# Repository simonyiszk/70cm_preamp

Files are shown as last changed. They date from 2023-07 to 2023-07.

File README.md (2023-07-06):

Előerősítő 70 cm-es sávra
===========

# Specifikáció
* 435 MHz középfrekcencia
* 23 MHz sávszélesség

# v02 változások
* Új erősítő: PGA-103+
* Új szűrő: SF2446E
* Kapcsrajz szimbólumok külön könyvtárba rendszerezése
* Rajzolatok külön könyvtárba rendszerezése
* cache fájlok hozzáadása .gitignore-hoz
* Bias Tee (tápfeladó)
* "RF" megjelölésű alkatrészek: rezonanciafrekvenciájuk kritikus

# PGA-103+
* Új erősítő: PGA-103+
* Új szűrő: SF2446E

# Megjegyzés
A 'lib-table' fájlok hozzáadják a kapcsrajz szimbólum és rajzolatokat tartalmazó fájlokat a könyvtárak közé.
Amennyiben ez mégsem történik meg, ezt manuálisan kell megtenni.

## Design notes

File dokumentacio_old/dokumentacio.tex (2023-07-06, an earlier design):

\begin{center}
	
	\Huge
	Előerősítő 70\,cm-es sávra
	
	\Large
	\url{https://github.com/simonyiszk/70cm_preamp}
	
	\Large
	HA5KFU projekt
	
	\Large
	Kiss Ádám (HA8KDA), Bazsó Márton (HA7BM), \\ Keresztes Botond, Agócs Dániel, Pápay Levente (HA3PL)
\end{center}

\tableofcontents

\listoffigures

\newpage

\section{Célkitűzés}
\label{sec:celkituzes}

Az erősítő hivatása, hogy a Schönherz kollégium tetejére telepített 70\,cm-es sávra készült antenna által fogott jeleket erősítse, közülük is elsősorban a SMOG-1 műholdét 437,345\,MHz-en.

\section{Kapcsolás}
\label{sec:kapcsolas}

Mivel az erősítő egy rádiófrekvencián elég \enquote{szennyezett} környékre kerül felszerelésre, így fontos egy jó szűrő alkalmazása ebben a fokozatban. Az akusztikus felületi hullámszűrők kitűnőek ilyen feladatokra, ugyanis nagyon meredek levágást biztosítanak a sávszéleken. Egy ilyen alkatrészt fellelni sem volt egyszerű, de beszerezni még bonyolultabbnak bizonyult, de végül a mouseren keresztül valahogyan sikerült. A választás az SF2446E\cite{SAW} néven futó áramkörre esett, melynek a minimum beszerzési mennyisége 10\,db volt.

Mint a legtöbb vételi berendezésben, itt is egy alacsony zajú előerősítő kerül a vételi lánc elejére. Előzőekben már épült egy hasonló kapcsolás egy ADL5523\cite{ADL}-as IC felhasználásával, de amikor kiderült, hogy az akusztikus szűrőből minimum 10-et kell rendelnünk, felmerült az ötlet, hogy gyártsunk le 10\,db áramkört, és a maradékra majd valahonnan kerítünk vevőt -- végül nem kellett sokat keresni, a nagy részük elkelt a klubon belül. Erősítőnek végül a Mini-Circuits PGA-103+\cite{PGA} terméke került kiválasztásra -- szintén a mouserről -- ugyanis kellően alacsony a zajtényezője, valamint 22\,dB erősítést ígér 400\,MHz-en, és végül, de nem utolsó sorban olcsóbb, mint egy ADL5523\cite{ADL}-as.

\begin{figure}[!ht]
	\centering
	
	\caption{Az előerősítő kapcsolása}
	\label{fig:LNA_sch}
\end{figure}

Alapesetben az erősítő a szűrő elé kerülne, ugyanis az eredő rendszernek így kedvezőbb lesz a jel-zaj viszonya. Viszont mint említésre került, a telepítési hely RF szempontból elég \enquote{szennyezett}, így félő, hogy a nagy sávszélességű erősítőnket könnyen túlvezérlik a számunkra érdektelen jelek. Ebből a meggondolásból a szűrőt az erősítő elé helyeztük, hogy csökkentsük a bele jutó összteljesítményt.

Amikor a NYÁK már majdnem gyártásba lett adva, Levente felhívta a figyelmünket egy kiegészítő dokumentumra\cite{PGA_comp}, mely az erősítőhöz megad egy kompenzáló hálózatot, ugyanis nélküle az áramkör 100\,MHz alatt nem lenne stabil. Így ez a 3 passzív alkatrészből álló kiegészítés az utolsó pillanatban még a tervre került. A végleges kapcsolás az \ref{fig:LNA_sch}-es ábrán látható.

\section{NYÁK}
\label{sec:nyak}

A hordozót elég kis méretűre meg lehetett csinálni, ugyanis mindösszesen 7 alkatrészt tartalmaz. A jelet vivő tápvonal úgy lett kialakítva, hogy a hullámimpedanciája 50\,$\Omega$-os legyen, ez főként azért lett ilyenre megcsinálva, hogy Marci gyakorolja CST-s szimulációs képességeit. Az elkészült rajzolat a \ref{fig:nyak}-es ábrán látható, mely egy kétrétegű, 1\,mm vastag hordozóra lett elkészítve.

\begin{figure}[!ht]
	\centering
	\begin{subfigure}[b]{0.49\textwidth}
		
		\caption{NYÁK eleje}
		\label{fig:nyak_elol}
	\end{subfigure}
	\begin{subfigure}[b]{0.49\textwidth}
		
		\caption{NYÁK hátulja}
		\label{fig:nyak_hatul}
	\end{subfigure}
	\caption{NYÁK terv a KiCAD 3D nézetében}
	\label{fig:nyak}
\end{figure}

Némi megfontolást igényelt, hogy az áramkörünk hordozóját az Elektronikai Technológia Tanszéken, vagy egy keleti üzemben gyártassuk le. A döntő szempont végül a sebesség volt, ugyanis a SMOG-1 indítása rohamosan közeledett, és szerettünk volna elkészülni vele, így az ETT-re esett a választás, ugyanis a keletről történő postázás időtartama viszonylag hosszú és olykor kiszámíthatatlan.

\section{Mérés 1}
\label{sec:meres1}

Miután elkészült néhány példány az áramkörből, ezek bemérésre kerültek a BME V1 épületében található Rohde \& Schwarz laboratóriumban. A méréshez használt eszközök egy R\&S ZVRE vektor hálózat analizátor, illetve egy R\&S ESCS30 típusú jelanalizátor, mellyel gerjedést mértünk a 100\,kHz - 1\,GHz tartományon -- utóbbi mérési eredmények külön nem kerültek elmentésre. Az áramkörök táplálásához Yume tápfeladóját, egy LM7805-öst, és egy R\&S NGMO2-es típusú labortápot használtunk, melynek kimenetét 8\,V-ra állítottuk.

A bemért áramkörök:

\begin{itemize}
	\item \#1: Szűrő + erősítő + kompenzáló hálózat
	\item \#2: Szűrő + erősítő + kompenzáló hálózat
	\item \#2.5: \#2-es áramkör javítás után (erősítő nem megfelelő forrasztása)
	\item \#3: Szűrő + erősítő
\end{itemize}

\newpage

Mivel a klubban nem voltak fellelhetők a kompenzáló hálózathoz szükséges pontos értékek, így az a következő értékekkel lett megvalósítva:

\begin{itemize}
	\item L1 220\,nH
	\item R1 150\,$\Omega$
	\item C1 330\,pF
\end{itemize}

Az áramkörökről összesen 14 mérés készült (ebből 13-at el is mentettünk, az utolsót elfelejtettük). A következőkben a legfontosabbak kerülnek ismertetésre, a többit pedig a Függelék (\ref{sec:fuggelek}) tartalmazza.

\subsection{\#1-es áramkör}
\label{subsec:1es_aramkor}

A \ref{fig:erosito1}-as ábrán az áramkör átvitele ($S_{21}$ paraméter) látható.

\begin{figure}[!ht]
	\centering
	
	\caption{\#1-es erősítő átvitele}
	\label{fig:erosito1}
\end{figure}

A mérés nagyságrendileg megegyezik az elvárásokkal. Az erősítőtől ebben a tartományban 22\,dB erősítést várunk, míg a szűrő nagyjából 2\,dB-t csillapít, avagy közel a várt eredményt kaptuk. A sávszélesség is jól egyezik a szűrő adatlapjában\cite{SAW} megadott 23\,MHz-el. Az erősítő áramfelvétele is (95\,mA) közel van az adatlapi\cite{PGA} értékhez, így összességében kijelenthető, hogy az áramkör az elvártnak megfelelően működik.

A vizsgálatok során nem találtunk gerjedésre utaló jeleket, így kijelenthető az is, hogy az alternatív értékekből összerakott kompenzáló hálózat is megfelelően ellátja feladatát.

%\newpage

\subsection{\#2-es áramkör}
\label{subsec:2es_aramkor}

Ez az áramkör először nem működött rendeltetésszerűen, ugyanis az erősítése gyanúsan alacsony volt. Egy gyors mikroszkóp alatti szemrevételezés után kiderült, hogy ennek oka, a nem megfelelően beforrasztott erősítő volt. A hiba javítása után a \ref{fig:erosito2}-es ábrán látható átvitelt kaptuk.

\begin{figure}[!ht]
	\centering
	
	\caption{\#2.5-ös erősítő átvitele}
	\label{fig:erosito2}
\end{figure}

Látható, hogy az átvitel jellege megegyezik az \#1-es áramkörnél mérttel, így erről is elmondható, hogy megfelelően működik. Ez a kapcsolás eleinte mutatott gerjedés gyanús jeleket, melyeket a későbbiek során nem sikerült reprodukálnunk. Feltételezhetően a spektrumbeli kitüremkedések egy tranziensjelenség miatt következtek be. A további mérések során az áramkör stabilnak bizonyult.

\subsection{\#3-as áramkör}
\label{3as_aramkor}

Miután megtaláltuk a kiegészítőt az adatlaphoz\cite{PGA_comp}, kíváncsiak voltunk, hogy vajon hogyan viselkedne az áramkör, ha nem építjük bele az ajánlott kompenzáló hálózatot. Ezért a harmadik áramkör csak a szűrőt és az erősítőt tartalmazta. A mérés eredménye a \ref{fig:erosito3}-ös ábrán látható.

\begin{figure}[!ht]
	\centering
	
	\caption{\#3-as erősítő átvitele}
	\label{fig:erosito3}
\end{figure}

Megfigyelhető, hogy a szűrő amplitúdómenete az áteresztő sávban jóval hullámosabb az adatlapban\,\cite{SAW} és az előző mérésekben látottnál. Ez a szűrő illesztetlenségére utalhat, ami azért különös, mert elméletileg minden eszközünk ki- és bemeneti impedanciája is 50\,$\Omega$-os. Látható az is, hogy az erősítő bekapcsolásakor is csak -10\,dB az átvitel, ami nem éppen nevezhető erősítőnek. Ezt a kapcsolást is megvizsgáltuk gerjedés szempontjából, de itt sem tapasztaltunk semmi ráutaló jelet.

1-2 nappal a mérések után felmerült bennem, hogy lehet, ennél a kapcsolásnál is volt nem megfelelő forrasztás, ugyanis szerintem a kompenzáló hálózat hiányának nem szabadna ekkora csillapítást okoznia (30\,dB-lel voltunk az elvárt szint alatt). A szűrőnek a megváltozott amplitúdómenetéből valószínűsíthető, hogy összességében a kompenzálóhálózat hiánya befolyással van az áramkör viselkedésére, viszont nem zárható ki, hogy volt egyéb tényező -- a kiegészítő hálózaton kívül -- ami befolyásolta az eredményt. Ezért nem jelenthető ki egyértelműen, hogy ez a mérés a kompenzáló hálózat átvitelre gyakorolt hatását szemlélteti.

\section{Mérés 2}
\label{sec:meres2}

Miután az első mérésekkel igazoltuk, hogy az alapkoncepció működőképes, megrendeltük a szükséges passzív alkatrészeket és csatlakozókat\cite{90es_SMA}, majd ismét beköltöztünk egy délután erejéig a BME V1 épületében található Rohde \& Schwarz laboratóriumba, hogy beforrasszuk az áramköröket, és méréssel igazoljuk működésüket.

A méréshez használt eszközök egy R\&S ZVRE vektor hálózat analizátor, illetve egy R\&S ESCS30 típusú jelanalizátor, mellyel gerjedést mértünk a 100\,kHz - 1\,GHz tartományon -- utóbbi mérési eredmények külön nem kerültek elmentésre. Az áramkörök táplálásához Yume tápfeladóját, egy LM7805-öst, és egy R\&S NGMO2-es típusú labortápot használtunk, melynek kimenetét 8\,V-ra állítottuk. A mérési elrendezés a \ref{fig:elrendezes}-es ábrán látható -- a labortápot leszámítva.

\begin{figure}[!ht]
	\centering
	\begin{minipage}[b]{0.49\textwidth}
		
		\caption{Egy beforrasztott áramkör}
		\label{fig:beforrasztott}
	\end{minipage}
	\begin{minipage}[b]{0.49\textwidth}
		
		\caption{Mérési elrendezés}
		\label{fig:elrendezes}
	\end{minipage}
\end{figure}

A módszertanon annyit változtattunk az előző alkalomhoz képest, hogy a VNA-t úgy kalibráltuk, hogy a két portját összecsatoltuk, közbeiktatva a tápfeladót, és rákapcsolva a tápegységet. Így -- mint látni fogjuk -- a várthoz közelebbi eredményeket kaptunk, mint előző alkalommal, amikor csak a mérőkábelek lettek kikompenzálva.

Mivel a Lomex-ben nem voltak kaphatók pont azok az értékek, melyeket az előzőekben kipróbáltunk, így a kompenzáló hálózat értékei a következők lettek:

\begin{itemize}
	\item L1 330\,nH\cite{L1}
	\item R1 150\,$\Omega$\cite{R1}
	\item C1 330\,pF\cite{C1}
\end{itemize}

Az alábbi áramkörök kerültek megépítésre és bemérésre (az összes alkatrészt tartalmazzák, kivétel ahol másként van feltüntetve):

\begin{itemize}
\item \#0: \#7-es áramkör kompenzálóhálózat nélkül
\item \#2.5: lásd: \ref{sec:meres1} és \ref{subsec:2es_aramkor} pont
\item \#3.5: \#3-as áramkör javítás után (szűrő nem megfelelő forrasztása)
\item \#4
\item \#5
\item \#6
\item \#7
\item \#8
\end{itemize}

A nap végére az összes beforrasztott áramkör működőképes volt, és az elvártnak megfelelően üzemelt.

Mivel kiderült, hogy az előző alkalommal valóban egy rosszul beforrasztott áramkörön tanulmányoztuk a kompenzáló hálózat hatását, így megismételtük a mérést, ezúttal különös tekintettel a forrasztásra. A mérési eredményeket a \ref{fig:kompenzalo_halozat}-as ábra veti össze.

\begin{figure}[!ht]
	\centering
	\begin{subfigure}[b]{\textwidth}
		
		\caption{Kompenzáló hálózat nélkül}
		\label{fig:erosito0}
	\end{subfigure}
	\begin{subfigure}[b]{\textwidth}
		
		\caption{Kompenzáló hálózattal}
		\label{fig:erosito7}
	\end{subfigure}
	\caption{Kompenzálás hatásának vizsgálata}
	\label{fig:kompenzalo_halozat}
\end{figure}

Látható, hogy a két áramkör között nincsen jelentős eltérés az átviteli sávban, mindössze annyi különbség figyelhető meg, hogy a \ref{fig:erosito0} esetben az áteresztő sáv enyhén felfelé tolódott el frekvenciatartományban. A jelanalizátoron végzett mérés sem mutatott észlelhető gerjedést a 100\,kHz - 1\,GHz-es tartományban.

Végeredményben a mi méréseink alapján ezen alkalmazáshoz nem nélkülözhetetlen a kompenzáló hálózat, ennek ellenére az ajánlásnak megfelelően beforrasztottuk őket.

\subsection{Árnyékolás}
\label{subsec:arnyekolas}

Mivel a HA5KFU-nak gyártott példány egy erősen \enquote{RF szennyezett} környezetbe kerül -- Schönherz teteje -- így úgy döntöttünk, hogy a tetőre kerülő példányt (\#3.5-ös áramkör) bedobozoljuk, hogy védjük ezen zavarok ellen. Az árnyékoló dobozba\cite{doboz} szerelt áramkör a \ref{fig:arnyekolas}-es ábrán látható (az egyes csatlakozók funkcióját természetesen feliratozással jeleztük a szintén az ábrán látható alkoholos filctollal). Az egyszerűbb dobozolás érdekében itt a korábban látott $90^{\circ}$-os SMA csatlakozók helyett egyeneseket használtunk\cite{egyenes_SMA}.

\begin{figure}[!ht]
	\centering
	
	\caption{Az árnyékolt erősítő}
	\label{fig:arnyekolas}
\end{figure}

A jelanalizátorral végzett mérések a következő eredményt adták:

Árnyékolás nélkül a spektrumban kb. -80\,dBm szintű csúcsok láthatóak 100\,MHz, 800\,MHz és 900\,MHz környékén, melyek rendre az FM adók, LTE hálózat illetve a GSM hálózat. Az árnyékolt áramkör összeszedett zavarait nem tudtuk kimutatni, ugyanis nem türemkedtek az analizátor -90\,dBm-es zajszintje fölé.

A mérés alapján kijelenthető, hogy az árnyékolás kedvező hatással van a zajszintre, az összeszedett zavarok szintjét -90\,dBm alá csökkentette (a mérés helyszínén).

\subsection{Ellenpárhuzamos diódapár}
\label{subsec:diodak}

Tartunk tőle, hogy a tetőre kihelyezett gamma illesztésű antenna elektrosztatikusan feltöltődik, és egy esetleges kisülés károsítja a felületi szűrőnket. Ennek orvoslására egy ellentétes polaritással bekötött diódapárt helyeztünk a szűrő elé (a \ref{fig:diodak}-es ábrának megfelelően), hogy az esetlegesen felgyülemlő töltéseket ki tudja egyenlíteni. A választásnál fontos volt, hogy kis kapacitású diódákat\cite{dioda} használjunk, mivel ezek esetlegesen elhangolhatnák a szűrőt, és az átviteli sávot.

\begin{figure}[!ht]
	\centering
	
	\caption{Nem párhuzamos diódapár}
	\label{fig:diodak}
\end{figure}

Mivel ez egy utólagos ötlet volt, így ezen alkatrészeknek nem lett külön hely kialakítva a NYÁK-on, hanem a csatlakozó lábai közé lettek \enquote{begányolva}.

A beépítés utáni mérések azt mutatták, hogy a beiktatott diódák nem befolyásolják kimutatható mértékben az erősítő átvitelét.

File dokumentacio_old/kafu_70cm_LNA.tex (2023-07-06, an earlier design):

\documentclass[12pt,a4paper,oneside]{article}
\usepackage{geometry}
	\geometry                  %margók és lapméret beállítása
		{
			a4paper,
			top=20mm,
			bottom=25mm,
			left=25mm,
			right=25mm
		}
	\pagestyle{plain}           %fejléc üres, lábléc az oldalszámot tartalmazza
\usepackage{setspace}           %sorközt lehet beállítani
	\singlespacing              %egyszeres sorköz
\usepackage{indentfirst}        %bekezdések formázása
	\setlength{\parindent}{1em} %bekezdés első sorának behúzása
	\setlength{\parskip}{6pt}   %bekezdések közötti távolság
\usepackage[autostyle]{csquotes}%idézőjelek helyes formázásához
	
\usepackage[utf8]{inputenc}     %karakterkódolás
\usepackage[magyar]{babel}      %helyesírás-ellenőrzés
\usepackage[T1]{fontenc}        %szimbólumkódolás

\usepackage{amsmath}            %matematikai képletekhez
\usepackage{amssymb}            %több matematikai jelölés (automatikusan betölti az 'amsfonts' csomagot)
\usepackage{graphicx}           %képek beillesztéséhez (valószínűleg betölti a 'graphics' csomagot, de nem találtam erre egyértelmű hivatkozást)
	\graphicspath               %képek elérési útvonala, szabadon bővíthető/csökkenthető
	{
		{./}
		{./kepek/}
		{./octave/}
	}
\usepackage{enumitem}           %felsorolásokat lehet vele formázni
\usepackage{titling}            %title, author, stb. definiálásához, használatához
\usepackage{hyperref}           %a hivatkozásokat kezeli
	\hypersetup                 %a hivatkozásokat lehet formálni
	{
		colorlinks=true,        %linkek színezésének engedélyezése
		citecolor=black,        %dokumentumon belüli hivatkozás színe
		linkcolor=black,          %valami másféle dokumentumon belüli hivatkozás színe
		urlcolor=blue,          %weblaphivatkozások színe
	}
\usepackage[center]{caption}    %képaláírásokat alapból középre igazítja
\usepackage{subcaption}         %subfigure környezethez
\usepackage{float}              %'lebegő' objektumok (pl. képek, táblázatok) pozícionálására

\begin{document}
	\include{dokumentacio}
	\include{fuggelek}
\end{document}

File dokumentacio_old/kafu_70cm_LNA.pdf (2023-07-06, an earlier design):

# Előerősítő 70 cm-es sávra

## https://github.com/simonyiszk/70cm_preamp

## HA5KFU projekt

Kiss Ádám (HA8KDA), Bazsó Márton (HA7BM),

## Keresztes Botond, Agócs Dániel, Pápay Levente (HA3PL)

## Tartalomjegyzék

1. Célkitűzés | 3
2. Kapcsolás | 3
3. NYÁK | 4
4. Mérés 1 | 4
4.1. #1-es áramkör | | 5
4.2. #2-es áramkör | | 5
4.3. #3-as áramkör | | 6
5. Mérés 2 | 7
5.1. Árnyékolás | 10
5.2. Ellenpárhuzamos diódapár | 10
6. Függelék | 12
6.1. Mérési eredmények grafikusan | 13

## Ábrák jegyzéke

1. | Az előerősítő kapcsolása | | 3
2. | NYÁK terv a KiCAD 3D nézetében | | 4
3. | #1-es erősítő átvitele | | 5
4. | #2.5-ös erősítő átvitele | | 6
5. | #3-as erősítő átvitele | | 7
6. | Egy beforrasztott áramkör | | 8
7. | Mérési elrendezés | | 8
8. | Kompenzálás hatásának vizsgálata | | 9

9. Az árnyékolt erősítő | 10
10. Nem párhuzamos diódapár | 11
11. #1-es erősítő 1 MHz - 1 GHz, erősítő KI | 13
12. #1-es erősítő 400 MHz - 480 MHz, erősítő KI | 13
13. #1-es erősítő 1 MHz - 1 GHz, erősítő BE | 14
14. #1-es erősítő 400 MHz - 480 MHz, erősítő BE | 14
15. #2-es erősítő 1 MHz - 1 GHz, erősítő KI | 15
16. #2-es erősítő 400 MHz - 480 MHz, erősítő KI | 15
17. #2-es erősítő 1 MHz - 1 GHz, erősítő BE | 16
18. #2-es erősítő 400 MHz - 480 MHz, erősítő BE | 16
19. #2.5-ös erősítő 400 MHz - 480 MHz, erősítő BE | 17
20. #3-as erősítő 1 MHz - 1 GHz, erősítő KI | 17
21. #3-as erősítő 400 MHz - 480 MHz, erősítő KI | 18
22. #3-as erősítő 1 MHz - 1 GHz, erősítő BE | 18
23. #3-as erősítő 400 MHz - 480 MHz, erősítő BE | 19
24. #0-ás erősítő 1 MHz - 1 GHz, erősítő BE | 19
25. #0-ás erősítő 400 MHz - 480 MHz, erősítő BE | 20
26. #2.5-ös erősítő 1 MHz - 1 GHz, erősítő BE | 20
27. #2.5-ös erősítő 400 MHz - 480 MHz, erősítő BE | 21
28. #3.5-ös erősítő 1 MHz - 1 GHz, erősítő BE | 21
29. #3.5-ös erősítő 400 MHz - 480 MHz, erősítő BE | 22
30. #4-es erősítő 1 MHz - 1 GHz, erősítő BE | 22
31. #4-es erősítő 400 MHz - 480 MHz, erősítő BE | 23
32. #5-ös erősítő 1 MHz - 1 GHz, erősítő BE | 23
33. #5-ös erősítő 400 MHz - 480 MHz, erősítő BE | 24
34. #6-os erősítő 1 MHz - 1 GHz, erősítő BE | 24
35. #6-os erősítő 400 MHz - 480 MHz, erősítő BE | 25
36. #7-es erősítő 1 MHz - 1 GHz, erősítő BE | 25
37. #7-es erősítő 400 MHz - 480 MHz, erősítő BE | 26
38. #8-as erősítő 1 MHz - 1 GHz, erősítő BE | 26
39. #8-as erősítő 400 MHz - 480 MHz, erősítő BE | 27

## 1. Célkitűzés

Az erősítő hivatása, hogy a Schönherz kollégium tetejére telepített 70 cm-es sávra készült antenna által fogott jeleket erősítse, közülük is elsősorban a SMOG-1 műholdét 437,345 MHz-en.

## 2. Kapcsolás

Mivel az erősítő egy rádiófrekvencián elég „szennyezett” környékre kerül felszerelésre, így fontos egy jó szűrő alkalmazása ebben a fokozatban. Az akusztikus felületi hullámszűrők kitűnőek ilyen feladatokra, ugyanis nagyon meredek levágást biztosítanak a sávszéleken. Egy ilyen alkatrészt fellelni sem volt egyszerű, de beszerezni még bonyolultabbnak bizonyult, de végül a mouseren keresztül valahogyan sikerült. A választás az SF2446E[1] néven futó áramkörre esett, melynek a minimum beszerzési mennyisége 10 db volt.

Mint a legtöbb vételi berendezésben, itt is egy alacsony zajú előerősítő kerül a vételi lánc elejére. Előzőekben már épült egy hasonló kapcsolás egy ADL5523[2]-as IC felhasználásával, de amikor kiderült, hogy az akusztikus szűrőből minimum 10-et kell rendelnünk, felmerült az ötlet, hogy gyártsunk le 10 db áramkört, és a maradékra majd valahonnan kerítünk vevőt – végül nem kellett sokat keresni, a nagy részük elkelt a klubon belül. Erősítőnek végül a Mini-Circuits PGA-103+[3] terméke került kiválasztásra – szintén a mouserről – ugyanis kellően alacsony a zajtényezője, valamint 22 dB erősítést ígér 400 MHz-en, és végül, de nem utolsó sorban olcsóbb, mint egy ADL5523[2]-as.

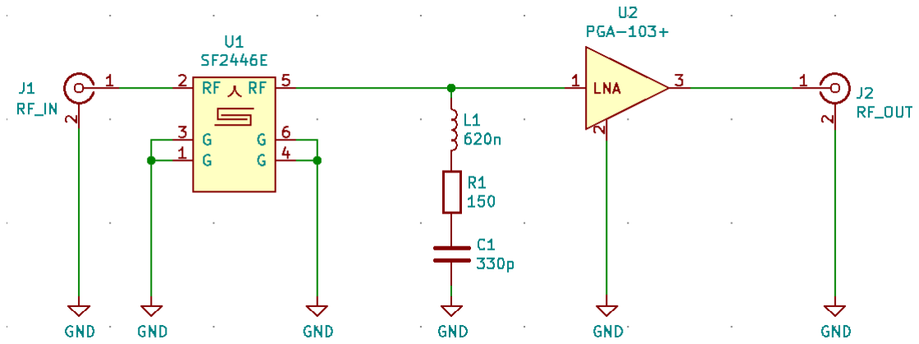
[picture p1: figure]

1. ábra. Az előerősítő kapcsolása

Alapesetben az erősítő a szűrő elé kerülne, ugyanis az eredő rendszernek így kedvezőbb lesz a jel-zaj viszonya. Viszont mint említésre került, a telepítési hely RF szempontból elég „szennyezett”, így félő, hogy a nagy sávszélességű erősítőnket könnyen túlvezérlik a számunkra érdektelen jelek. Ebből a meggondolásból a szűrőt az erősítő elé helyeztük, hogy csökkentsük a bele jutó összteljesítményt.
Amikor a NYÁK már majdnem gyártásba lett adva, Levente felhívta a figyelmünket egy kiegészítő dokumentumra[4], mely az erősítőhöz megad egy kompenzáló hálózatot, ugyanis nélküle az áramkör 100 MHz alatt nem lenne stabil. Így ez a 3 passzív alkatrészből álló kiegészítés az utolsó pillanatban még a tervre került. A végleges kapcsolás az 1-es ábrán látható.

## 3. NYÁK

A hordozót elég kis méretűre meg lehetett csinálni, ugyanis mindösszesen 7 alkatrészt tartalmaz. A jelet vivő tápvonal úgy lett kialakítva, hogy a hullámimpedanciája 50 Ω-os legyen, ez főként azért lett ilyenre megcsinálva, hogy Marci gyakorolja CST-s szimulációs képességeit. Az elkészült rajzolat a 2-es ábrán látható, mely egy kétrétegű, 1 mm vastag hordozóra lett elkészítve.

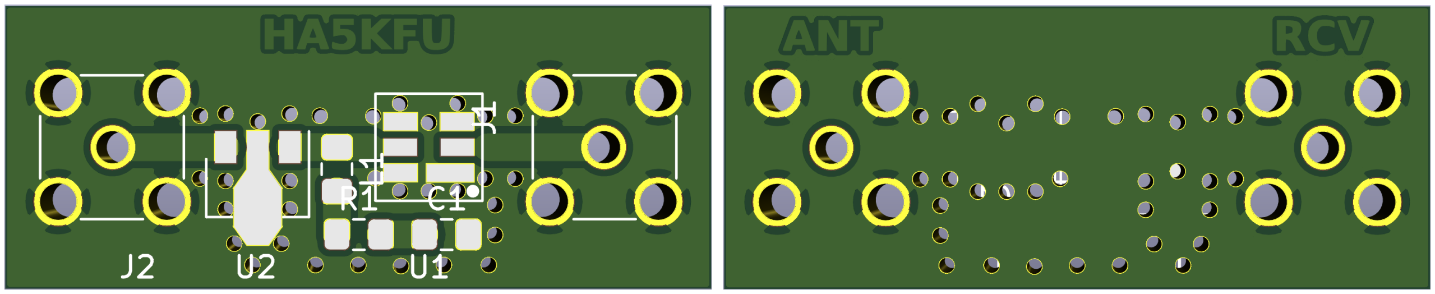
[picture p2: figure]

(a) NYÁK eleje | (b) NYÁK hátulja
2. ábra. NYÁK terv a KiCAD 3D nézetében

Némi megfontolást igényelt, hogy az áramkörünk hordozóját az Elektronikai Technológia Tanszéken, vagy egy keleti üzemben gyártassuk le. A döntő szempont végül a sebesség volt, ugyanis a SMOG-1 indítása rohamosan közeledett, és szerettünk volna elkészülni vele, így az ETT-re esett a választás, ugyanis a keletről történő postázás időtartama viszonylag hosszú és olykor kiszámíthatatlan.

## 4. Mérés 1

Miután elkészült néhány példány az áramkörből, ezek bemérésre kerültek a BME V1 épületében található Rohde & Schwarz laboratóriumban. A méréshez használt eszközök egy R&S ZVRE vektor hálózat analizátor, illetve egy R&S ESCS30 típusú jelanalizátor, mellyel gerjedést mértünk a 100 kHz - 1 GHz tartományon – utóbbi mérési eredmények külön nem kerültek elmentésre. Az áramkörök táplálásához Yume tápfeladóját, egy LM7805-öst, és egy R&S NGMO2-es típusú labortápot használtunk, melynek kimenetét 8 V-ra állítottuk.

A bemért áramkörök:

- #1: Szűrő + erősítő + kompenzáló hálózat
- #2: Szűrő + erősítő + kompenzáló hálózat
- #2.5: #2-es áramkör javítás után (erősítő nem megfelelő forrasztása)
- #3: Szűrő + erősítő

Mivel a klubban nem voltak fellelhetők a kompenzáló hálózathoz szükséges pontos értékek, így az a következő értékekkel lett megvalósítva:

- L1 220 nH
- R1 150 Ω
- C1 330 pF

Az áramkörökről összesen 14 mérés készült (ebből 13-at el is mentettünk, az utolsót elfelejtettük). A következőkben a legfontosabbak kerülnek ismertetésre, a többit pedig a Függelék (6) tartalmazza.

4.1. #1-es áramkör

A 3-as ábrán az áramkör átvitele (S21 paraméter) látható.

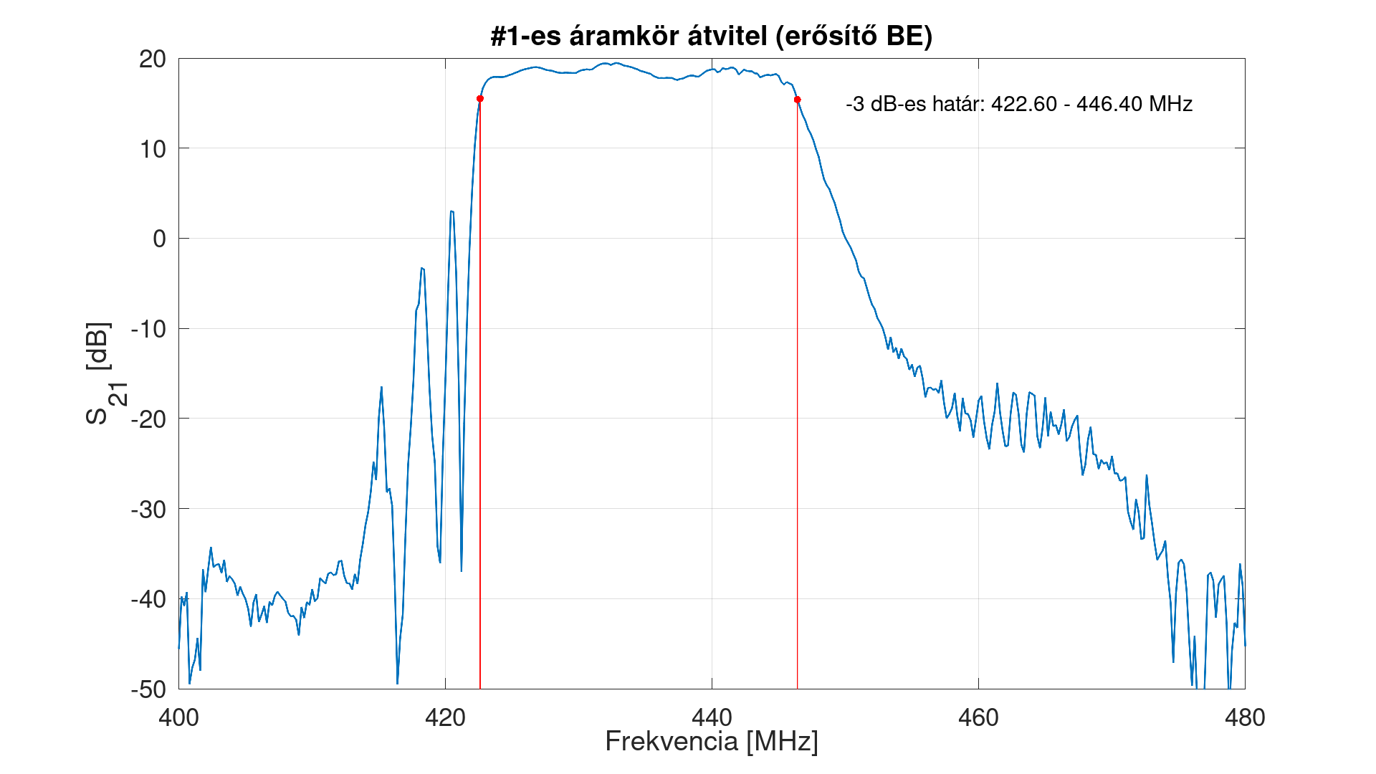
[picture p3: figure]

3. ábra. #1-es erősítő átvitele

A mérés nagyságrendileg megegyezik az elvárásokkal. Az erősítőtől ebben a tartományban 22 dB erősítést várunk, míg a szűrő nagyjából 2 dB-t csillapít, avagy közel a várt eredményt kaptuk. A sávszélesség is jól egyezik a szűrő adatlapjában[1] megadott 23 MHz-el. Az erősítő áramfelvétele is (95 mA) közel van az adatlapi[3] értékhez, így összességében kijelenthető, hogy az áramkör az elvártnak megfelelően működik.

A vizsgálatok során nem találtunk gerjedésre utaló jeleket, így kijelenthető az is, hogy az alternatív értékekből összerakott kompenzáló hálózat is megfelelően ellátja feladatát.

4.2. #2-es áramkör

Ez az áramkör először nem működött rendeltetésszerűen, ugyanis az erősítése gyanúsan alacsony volt. Egy gyors mikroszkóp alatti szemrevételezés után kiderült, hogy ennek oka, a nem megfelelően beforrasztott erősítő volt. A hiba javítása után a 4-es ábrán látható átvitelt kaptuk.

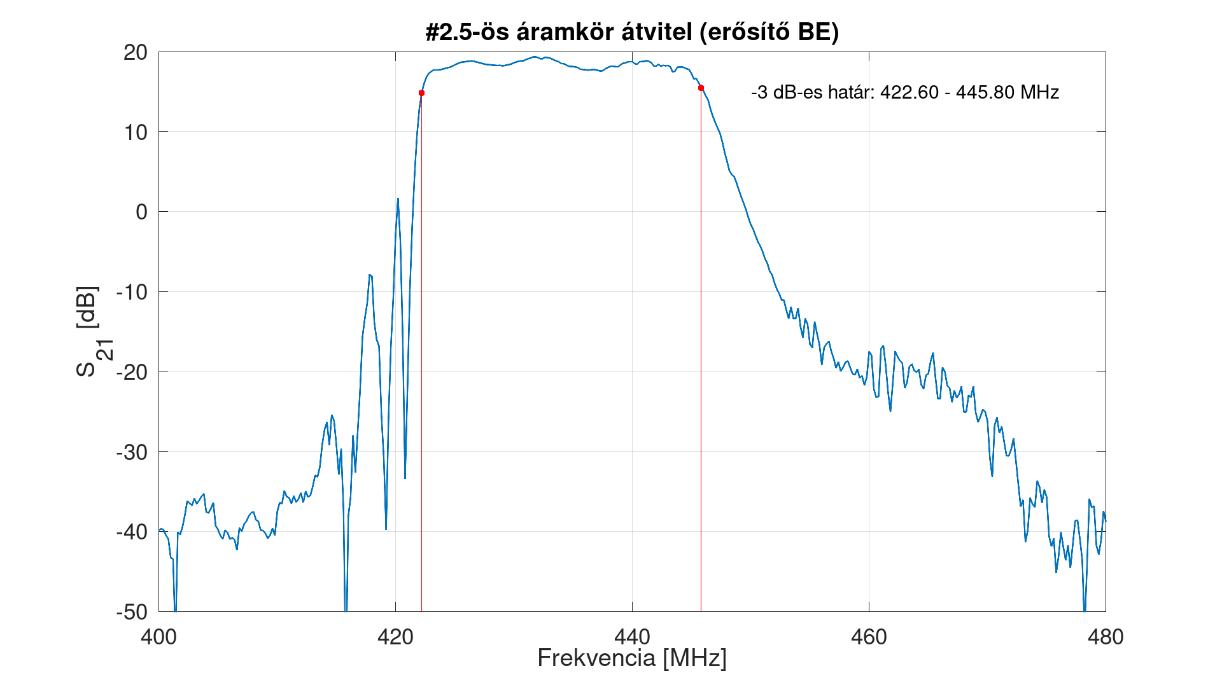
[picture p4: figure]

4. ábra. #2.5-ös erősítő átvitele

Látható, hogy az átvitel jellege megegyezik az #1-es áramkörnél mérttel, így erről is elmondható, hogy megfelelően működik. Ez a kapcsolás eleinte mutatott gerjedés gyanús jeleket, melyeket a későbbiek során nem sikerült reprodukálnunk. Feltételezhetően a spektrumbeli kitüremkedések egy tranziensjelenség miatt következtek be. A további mérések során az áramkör stabilnak bizonyult.

4.3. #3-as áramkör

Miután megtaláltuk a kiegészítőt az adatlaphoz[4], kíváncsiak voltunk, hogy vajon hogyan viselkedne az áramkör, ha nem építjük bele az ajánlott kompenzáló hálózatot. Ezért a harmadik áramkör csak a szűrőt és az erősítőt tartalmazta. A mérés eredménye a 5-ös ábrán látható.

Megfigyelhető, hogy a szűrő amplitúdómenete az áteresztő sávban jóval hullámosabb az adatlapban [1] és az előző mérésekben látottnál. Ez a szűrő illesztetlenségére utalhat, ami azért különös, mert elméletileg minden eszközünk ki- és bemeneti impedanciája is 50 Ω-os. Látható az is, hogy az erősítő bekapcsolásakor is csak -10 dB az átvitel, ami nem éppen nevezhető erősítőnek. Ezt a kapcsolást is megvizsgáltuk gerjedés szempontjából, de itt sem tapasztaltunk semmi ráutaló jelet.

1-2 nappal a mérések után felmerült bennem, hogy lehet, ennél a kapcsolásnál is volt nem megfelelő forrasztás, ugyanis szerintem a kompenzáló hálózat hiányának nem szabadna ekkora csillapítást okoznia (30 dB-lel voltunk az elvárt szint alatt). A szűrőnek a megváltozott amplitúdómenetéből valószínűsíthető, hogy összességében a kompenzálóhálózat hiánya befolyással van az áramkör viselkedésére, viszont nem zárható ki, hogy volt egyéb tényező – a kiegészítő hálózaton kívül – ami befolyásolta az eredményt. Ezért

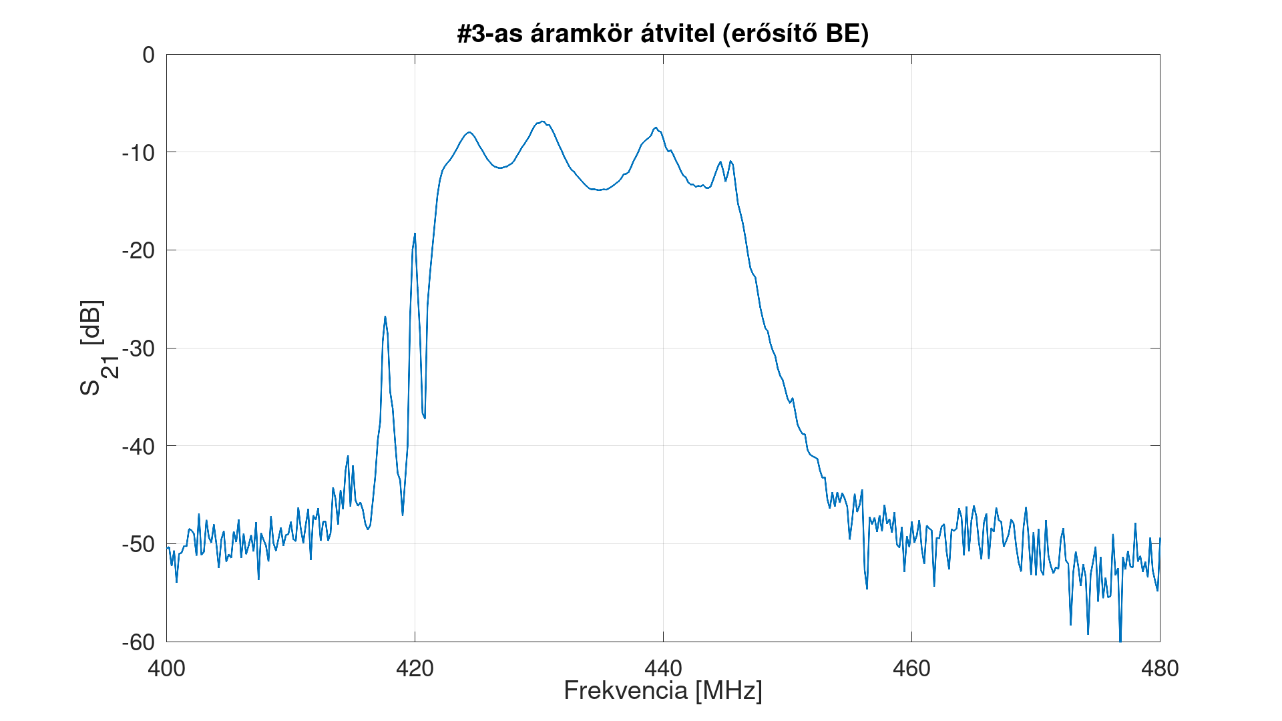
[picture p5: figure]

5. ábra. #3-as erősítő átvitele

nem jelenthető ki egyértelműen, hogy ez a mérés a kompenzáló hálózat átvitelre gyakorolt hatását szemlélteti.

## 5. Mérés 2

Miután az első mérésekkel igazoltuk, hogy az alapkoncepció működőképes, megrendeltük a szükséges passzív alkatrészeket és csatlakozókat[5], majd ismét beköltöztünk egy délután erejéig a BME V1 épületében található Rohde & Schwarz laboratóriumba, hogy beforrasszuk az áramköröket, és méréssel igazoljuk működésüket.

A méréshez használt eszközök egy R&S ZVRE vektor hálózat analizátor, illetve egy R&S ESCS30 típusú jelanalizátor, mellyel gerjedést mértünk a 100 kHz - 1 GHz tartományon – utóbbi mérési eredmények külön nem kerültek elmentésre. Az áramkörök táplálásához Yume tápfeladóját, egy LM7805-öst, és egy R&S NGMO2-es típusú labortápot használtunk, melynek kimenetét 8 V-ra állítottuk. A mérési elrendezés a 7-es ábrán látható – a labortápot leszámítva.

A módszertanon annyit változtattunk az előző alkalomhoz képest, hogy a VNA-t úgy kalibráltuk, hogy a két portját összecsatoltuk, közbeiktatva a tápfeladót, és rákapcsolva a tápegységet. Így – mint látni fogjuk – a várthoz közelebbi eredményeket kaptunk, mint előző alkalommal, amikor csak a mérőkábelek lettek kikompenzálva.

Mivel a Lomex-ben nem voltak kaphatók pont azok az értékek, melyeket az előzőekben kipróbáltunk, így a kompenzáló hálózat értékei a következők lettek:

- L1 330 nH[6]
- R1 150 Ω[7]
- C1 330 pF[8]

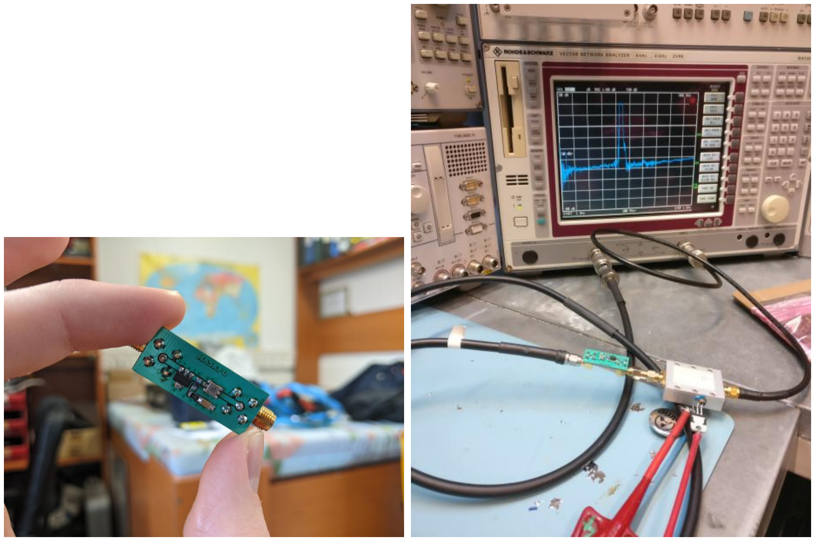
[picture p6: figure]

6. ábra. Egy beforrasztott áramkör | 7. ábra. Mérési elrendezés

Az alábbi áramkörök kerültek megépítésre és bemérésre (az összes alkatrészt tartalmazzák, kivétel ahol másként van feltüntetve):

- #0: #7-es áramkör kompenzálóhálózat nélkül
- #2.5: lásd: 4 és 4.2 pont
- #3.5: #3-as áramkör javítás után (szűrő nem megfelelő forrasztása)
- #4
- #5
- #6
- #7
- #8

A nap végére az összes beforrasztott áramkör működőképes volt, és az elvártnak megfelelően üzemelt.

Mivel kiderült, hogy az előző alkalommal valóban egy rosszul beforrasztott áramkörön tanulmányoztuk a kompenzáló hálózat hatását, így megismételtük a mérést, ezúttal különös tekintettel a forrasztásra. A mérési eredményeket a 8-as ábra veti össze.

Látható, hogy a két áramkör között nincsen jelentős eltérés az átviteli sávban, mindössze annyi különbség figyelhető meg, hogy a 8a esetben az áteresztő sáv enyhén felfelé

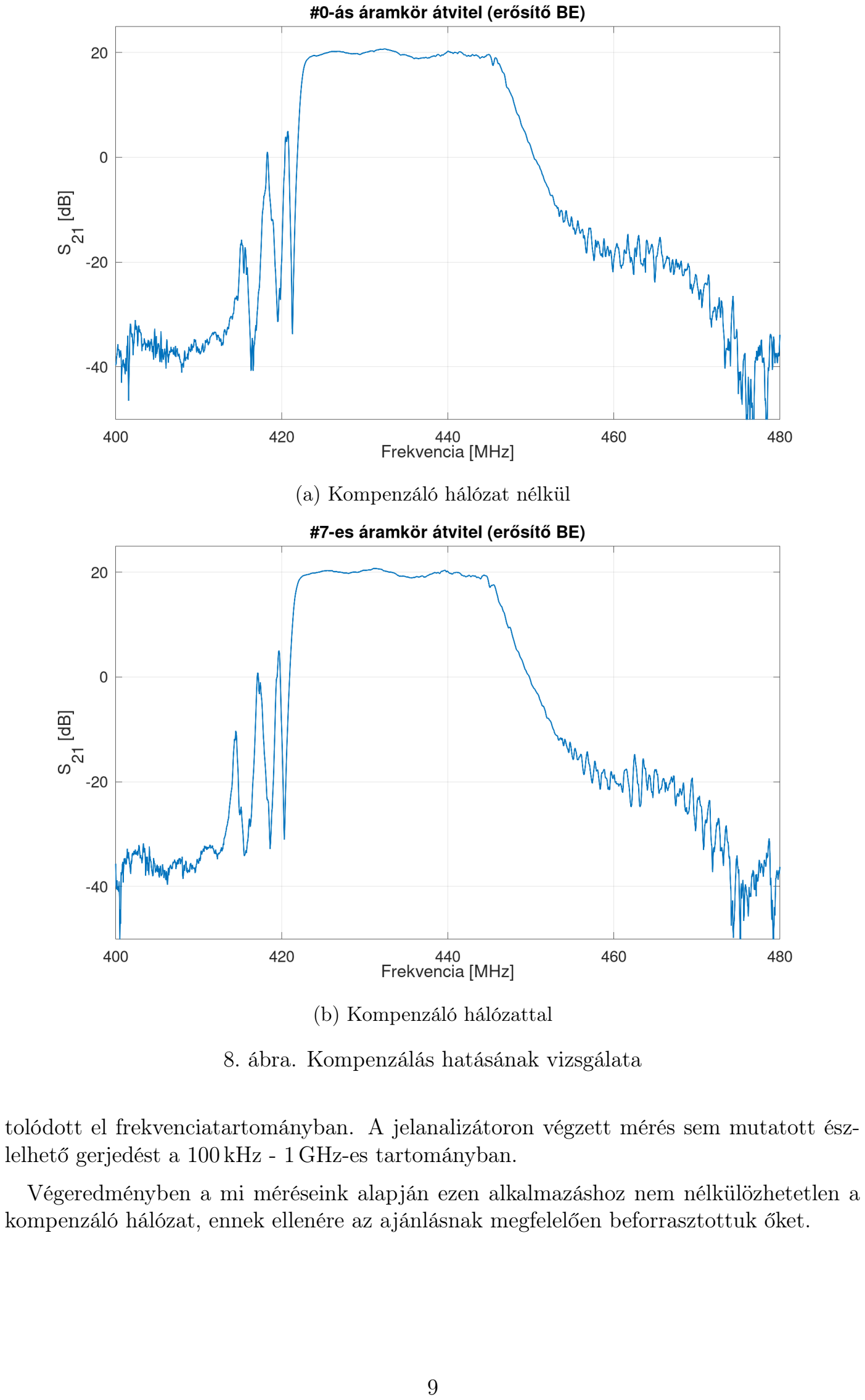
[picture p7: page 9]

(a) Kompenzáló hálózat nélkül
(b) Kompenzáló hálózattal
8. ábra. Kompenzálás hatásának vizsgálata

tolódott el frekvenciatartományban. A jelanalizátoron végzett mérés sem mutatott észlelhető gerjedést a 100 kHz - 1 GHz-es tartományban.

Végeredményben a mi méréseink alapján ezen alkalmazáshoz nem nélkülözhetetlen a kompenzáló hálózat, ennek ellenére az ajánlásnak megfelelően beforrasztottuk őket.

### 5.1. Árnyékolás

Mivel a HA5KFU-nak gyártott példány egy erősen „RF szennyezett” környezetbe kerül – Schönherz teteje – így úgy döntöttünk, hogy a tetőre kerülő példányt (#3.5-ös áramkör) bedobozoljuk, hogy védjük ezen zavarok ellen. Az árnyékoló dobozba[9] szerelt áramkör a 9-es ábrán látható (az egyes csatlakozók funkcióját természetesen feliratozással jeleztük a szintén az ábrán látható alkoholos filctollal). Az egyszerűbb dobozolás érdekében itt a korábban látott 90◦
-os SMA csatlakozók helyett egyeneseket használtunk[10].

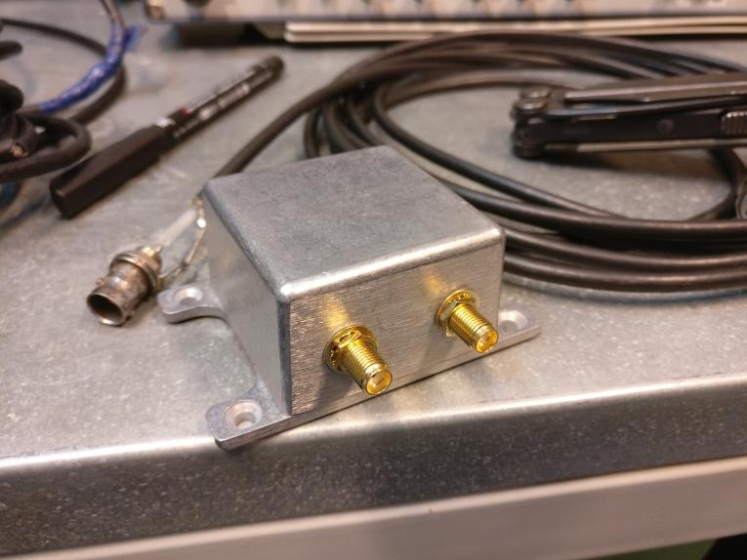
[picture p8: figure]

9. ábra. Az árnyékolt erősítő

A jelanalizátorral végzett mérések a következő eredményt adták:
Árnyékolás nélkül a spektrumban kb. -80 dBm szintű csúcsok láthatóak 100 MHz, 800 MHz és 900 MHz környékén, melyek rendre az FM adók, LTE hálózat illetve a GSM hálózat. Az árnyékolt áramkör összeszedett zavarait nem tudtuk kimutatni, ugyanis nem türemkedtek az analizátor -90 dBm-es zajszintje fölé.

A mérés alapján kijelenthető, hogy az árnyékolás kedvező hatással van a zajszintre, az összeszedett zavarok szintjét -90 dBm alá csökkentette (a mérés helyszínén).

### 5.2. Ellenpárhuzamos diódapár

Tartunk tőle, hogy a tetőre kihelyezett gamma illesztésű antenna elektrosztatikusan feltöltődik, és egy esetleges kisülés károsítja a felületi szűrőnket. Ennek orvoslására egy ellentétes polaritással bekötött diódapárt helyeztünk a szűrő elé (a 10-es ábrának megfelelően), hogy az esetlegesen felgyülemlő töltéseket ki tudja egyenlíteni. A választásnál fontos volt, hogy kis kapacitású diódákat[11] használjunk, mivel ezek esetlegesen elhangolhatnák a szűrőt, és az átviteli sávot.

Mivel ez egy utólagos ötlet volt, így ezen alkatrészeknek nem lett külön hely kialakítva

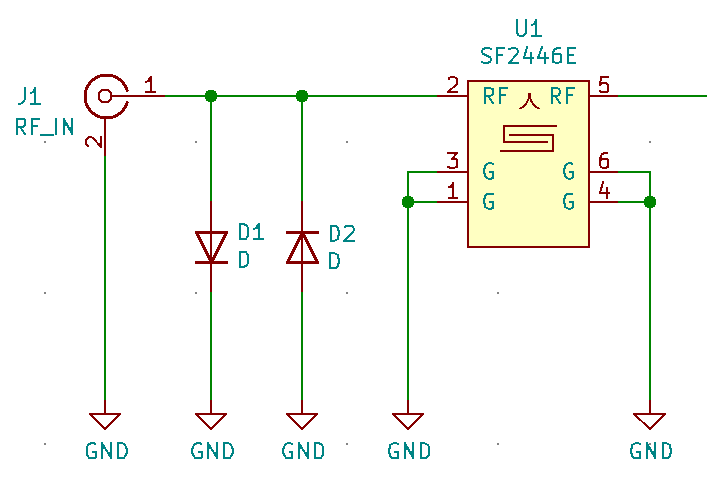
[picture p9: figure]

10. ábra. Nem párhuzamos diódapár

a NYÁK-on, hanem a csatlakozó lábai közé lettek „begányolva”.

A beépítés utáni mérések azt mutatták, hogy a beiktatott diódák nem befolyásolják kimutatható mértékben az erősítő átvitelét.

## 6. Függelék

## Hivatkozások

[1] SF2446E https://www.rfmi.co/pdf/Datasheet/sf2446e.pdf
[2] ADL5523 | https://www.analog.com/media/en/technical-documentation/
data-sheets/ADL5523.pdf (https://www.analog.com/media/en/technical-documentation/data-sheets/ADL5523.pdf)
[3] PGA-103+ https://www.minicircuits.com/pdfs/PGA-103+.pdf
[4] PGA-103+ | kompenzáló | hálózat | https://www.minicircuits.com/app/
AN60-064.pdf (https://www.minicircuits.com/app/AN60-064.pdf)
[5] 90◦
-os | SMA | csatlakozó | https://lomex.hu/hu/webshop/#page,0/search,
43-28-29/stype,1 (https://lomex.hu/hu/webshop/#page,0/search,43-28-29/stype,1)
[6] 330 nH | tekercs | https://lomex.hu/hu/webshop/#page,0/search,93-00-72/
stype,1 (https://lomex.hu/hu/webshop/#page,0/search,93-00-72/stype,1)
[7] 150 Ω | ellenállás | https://lomex.hu/hu/webshop/#page,0/search,80-10-76/
stype,1 (https://lomex.hu/hu/webshop/#page,0/search,80-10-76/stype,1)
[8] 330 pF | kondenzátor | https://lomex.hu/hu/webshop/#page,0/search,
82-07-43/stype,1 (https://lomex.hu/hu/webshop/#page,0/search,82-07-43/stype,1)
[9] Árnyékolódoboz https://hu.mouser.com/ProductDetail/Bud-Industries/CU-5470/?qs=J02F3jFhwzOGRdkfRTc5YA%3D%3D (https://hu.mouser.com/ProductDetail/Bud-Industries/CU-5470/?qs=J02F3jFhwzOGRdkfRTc5YA%3D%3D)
[10] Egyenes | SMA | csatlakozó | https://hu.mouser.com/ProductDetail/
Linx-Technologies/CONSMA008-G/?qs=vLWxofP3U2zf85vM2YDg9g%3D%3D (https://hu.mouser.com/ProductDetail/Linx-Technologies/CONSMA008-G/?qs=vLWxofP3U2zf85vM2YDg9g%3D%3D)
[11] Dióda https://lomex.hu/hu/webshop/#page,0/search,83-01-43/stype,1

### 6.1. Mérési eredmények grafikusan

11. ábra. #1-es erősítő 1 MHz - 1 GHz, erősítő KI

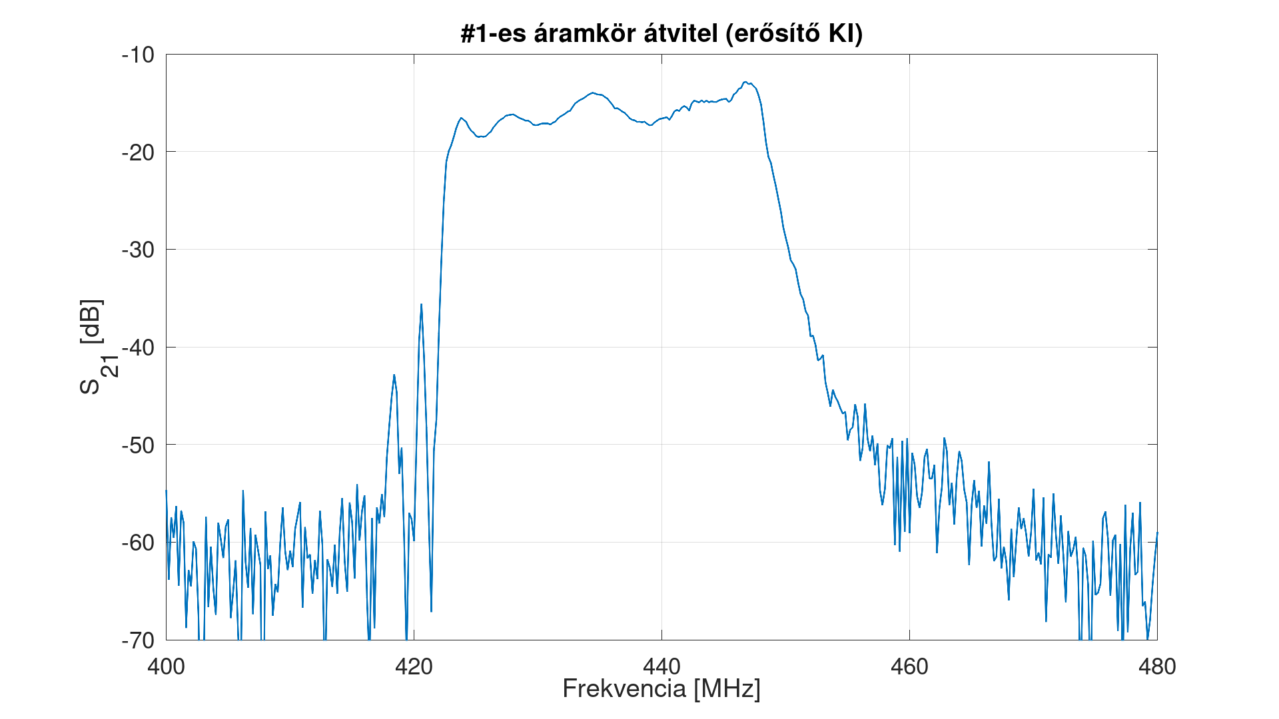
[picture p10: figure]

12. ábra. #1-es erősítő 400 MHz - 480 MHz, erősítő KI

13. ábra. #1-es erősítő 1 MHz - 1 GHz, erősítő BE
14. ábra. #1-es erősítő 400 MHz - 480 MHz, erősítő BE

15. ábra. #2-es erősítő 1 MHz - 1 GHz, erősítő KI

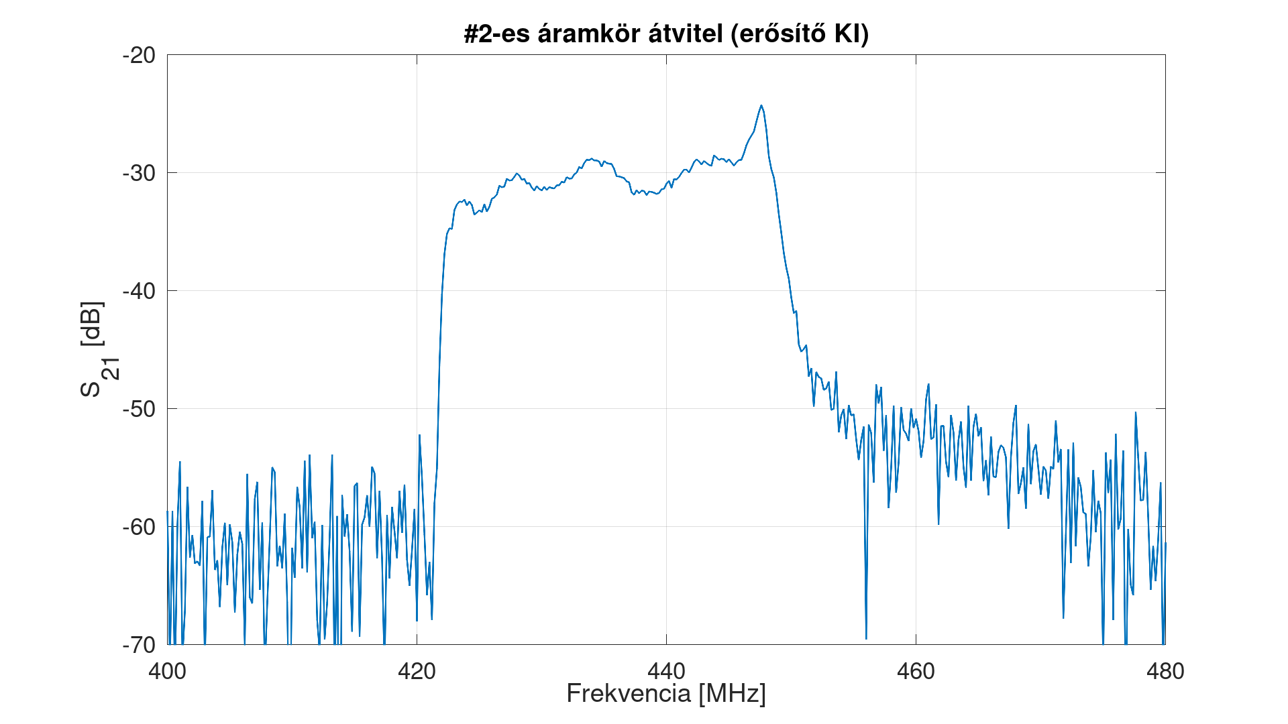
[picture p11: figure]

16. ábra. #2-es erősítő 400 MHz - 480 MHz, erősítő KI

17. ábra. #2-es erősítő 1 MHz - 1 GHz, erősítő BE

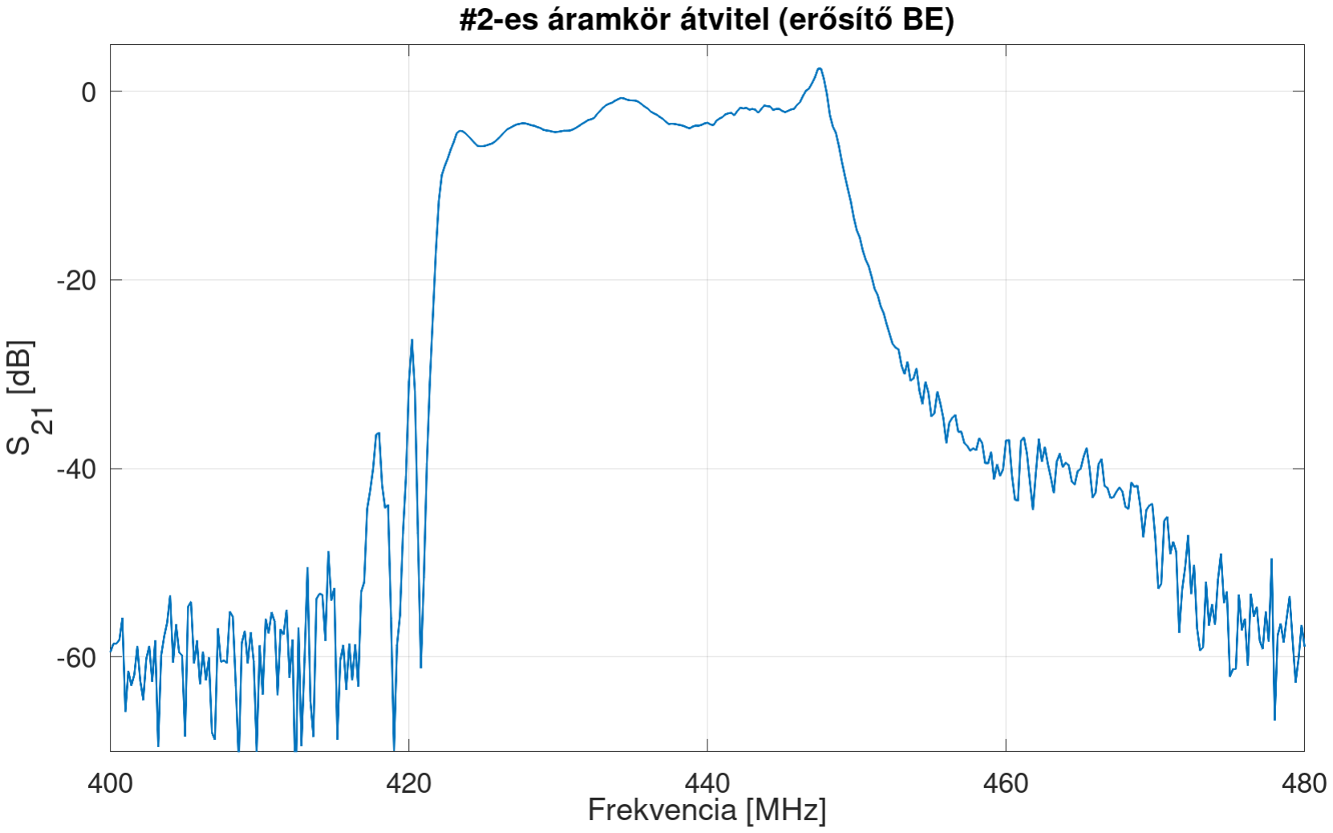
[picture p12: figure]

18. ábra. #2-es erősítő 400 MHz - 480 MHz, erősítő BE

19. ábra. #2.5-ös erősítő 400 MHz - 480 MHz, erősítő BE

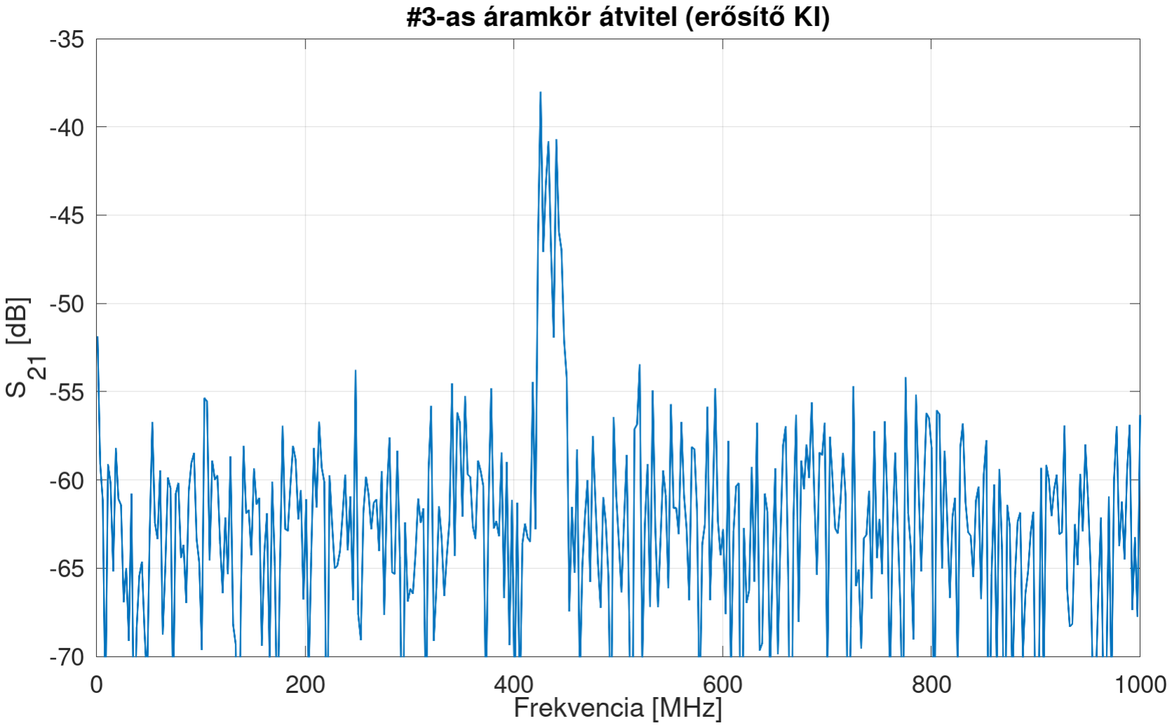
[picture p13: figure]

20. ábra. #3-as erősítő 1 MHz - 1 GHz, erősítő KI

21. ábra. #3-as erősítő 400 MHz - 480 MHz, erősítő KI

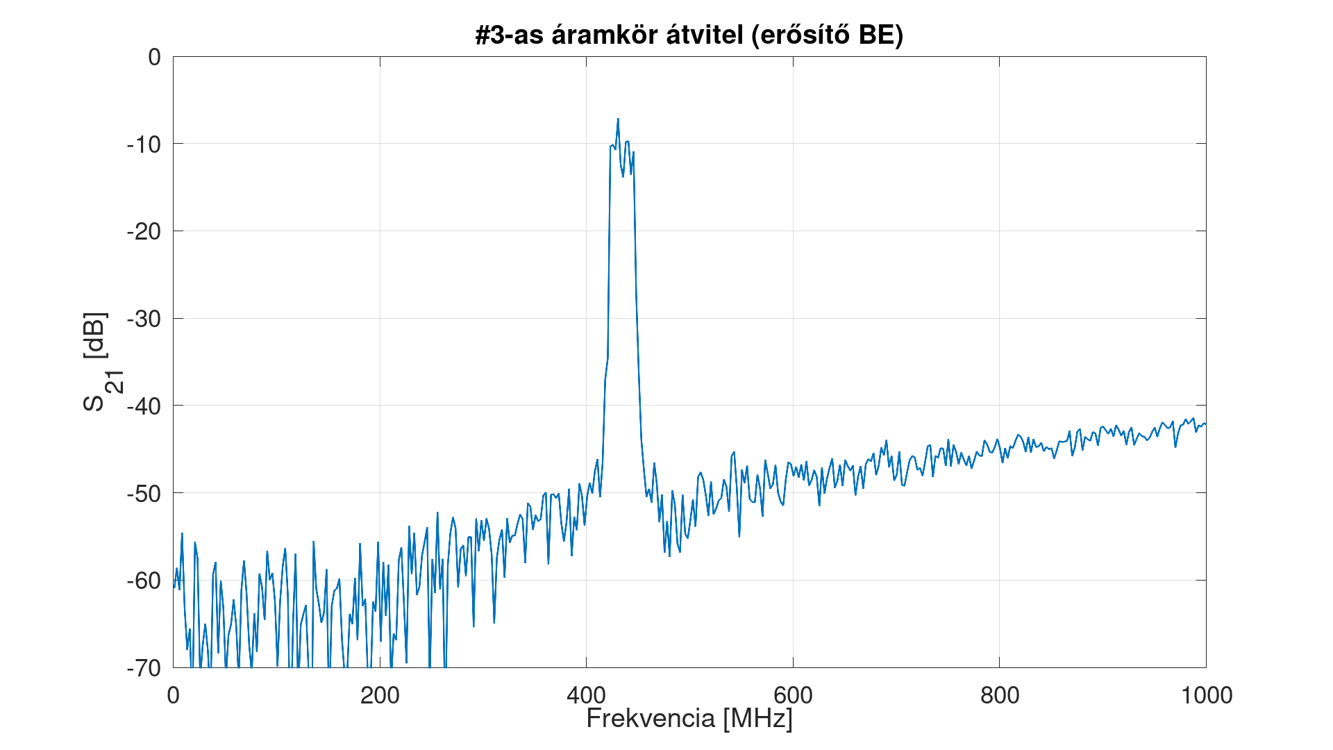
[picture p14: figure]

22. ábra. #3-as erősítő 1 MHz - 1 GHz, erősítő BE

23. ábra. #3-as erősítő 400 MHz - 480 MHz, erősítő BE

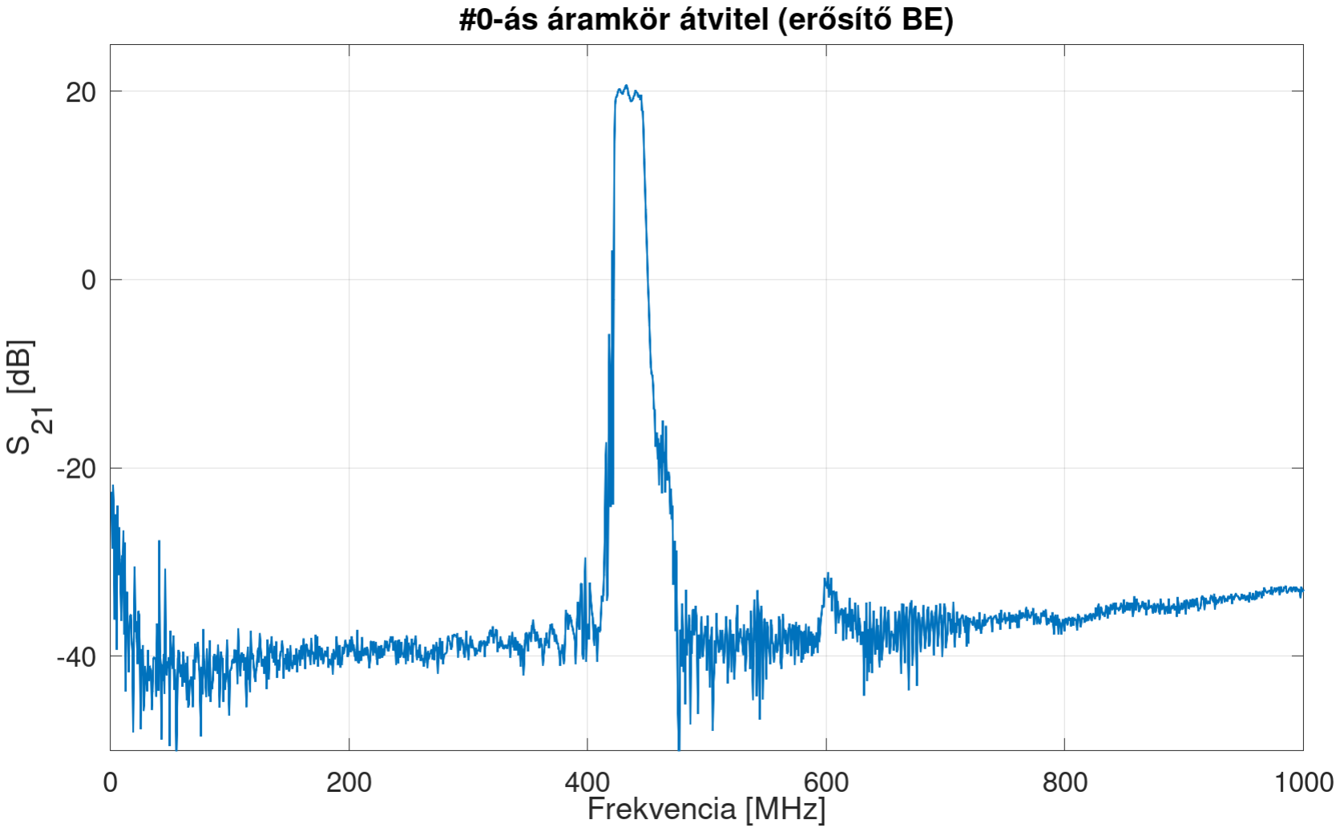
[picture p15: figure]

24. ábra. #0-ás erősítő 1 MHz - 1 GHz, erősítő BE

25. ábra. #0-ás erősítő 400 MHz - 480 MHz, erősítő BE

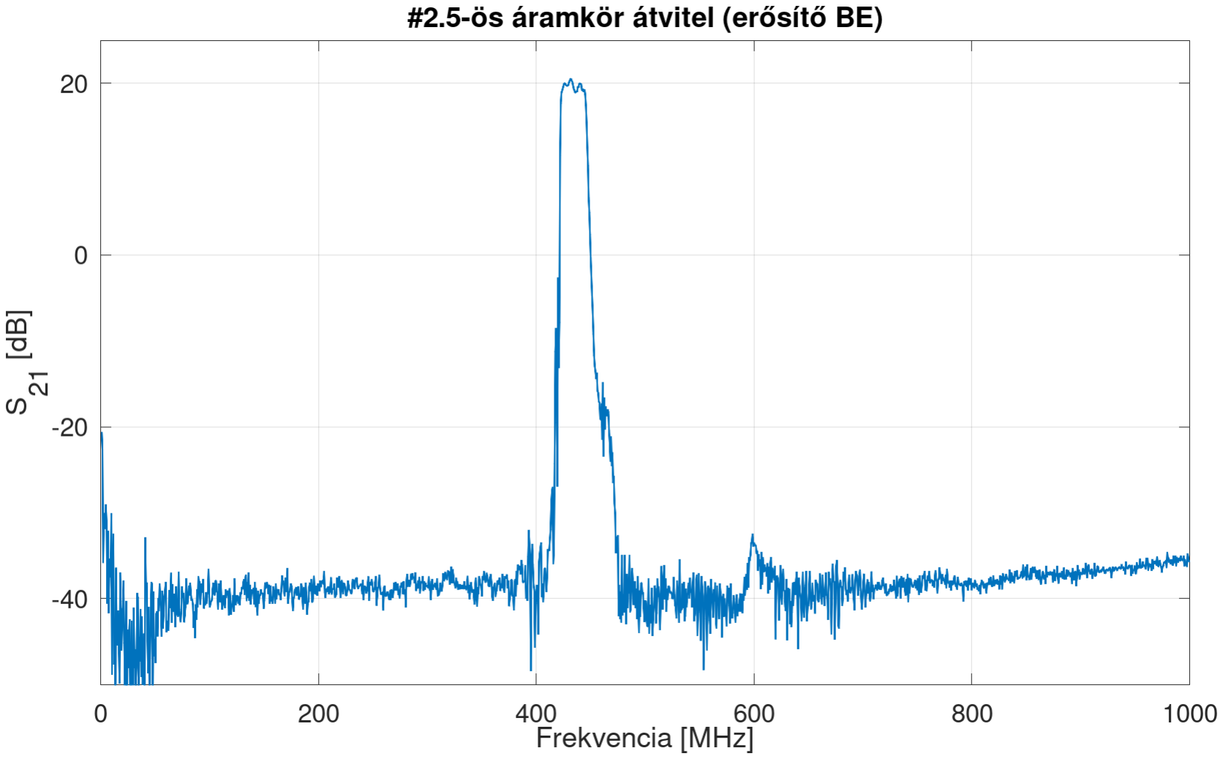
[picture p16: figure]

26. ábra. #2.5-ös erősítő 1 MHz - 1 GHz, erősítő BE

27. ábra. #2.5-ös erősítő 400 MHz - 480 MHz, erősítő BE

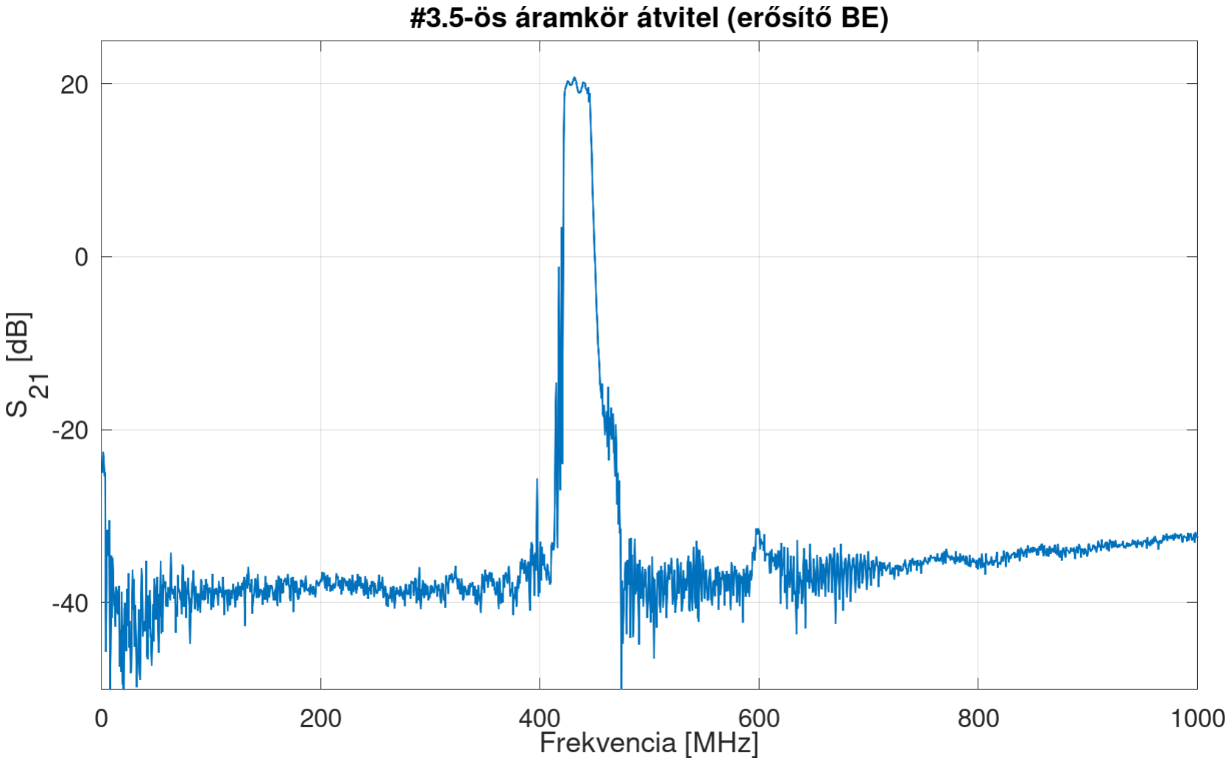
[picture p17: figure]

28. ábra. #3.5-ös erősítő 1 MHz - 1 GHz, erősítő BE

29. ábra. #3.5-ös erősítő 400 MHz - 480 MHz, erősítő BE

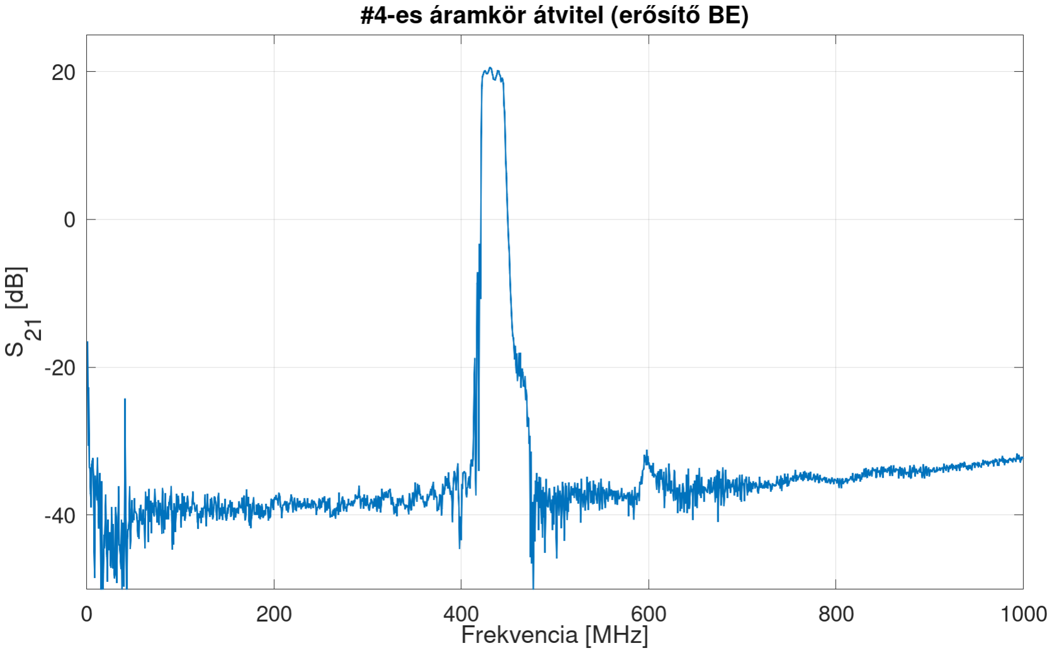
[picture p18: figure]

30. ábra. #4-es erősítő 1 MHz - 1 GHz, erősítő BE

31. ábra. #4-es erősítő 400 MHz - 480 MHz, erősítő BE

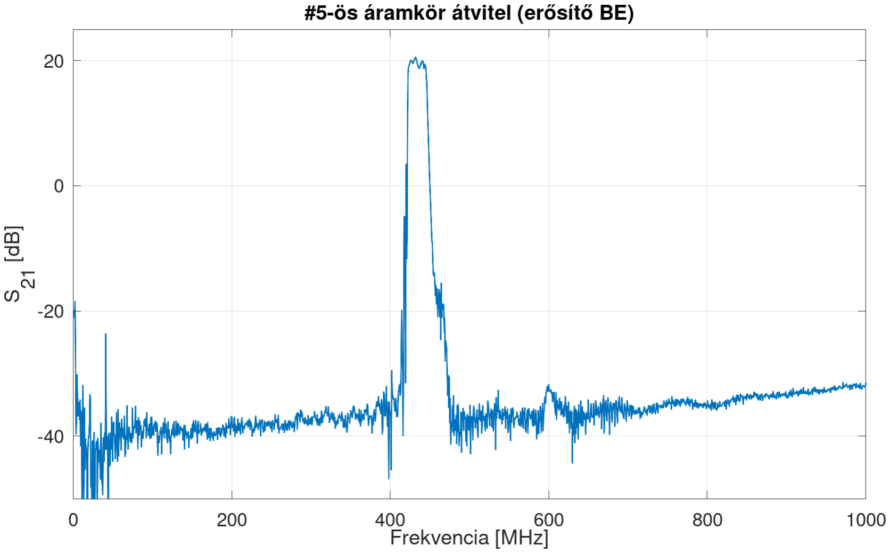
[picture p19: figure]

32. ábra. #5-ös erősítő 1 MHz - 1 GHz, erősítő BE

33. ábra. #5-ös erősítő 400 MHz - 480 MHz, erősítő BE

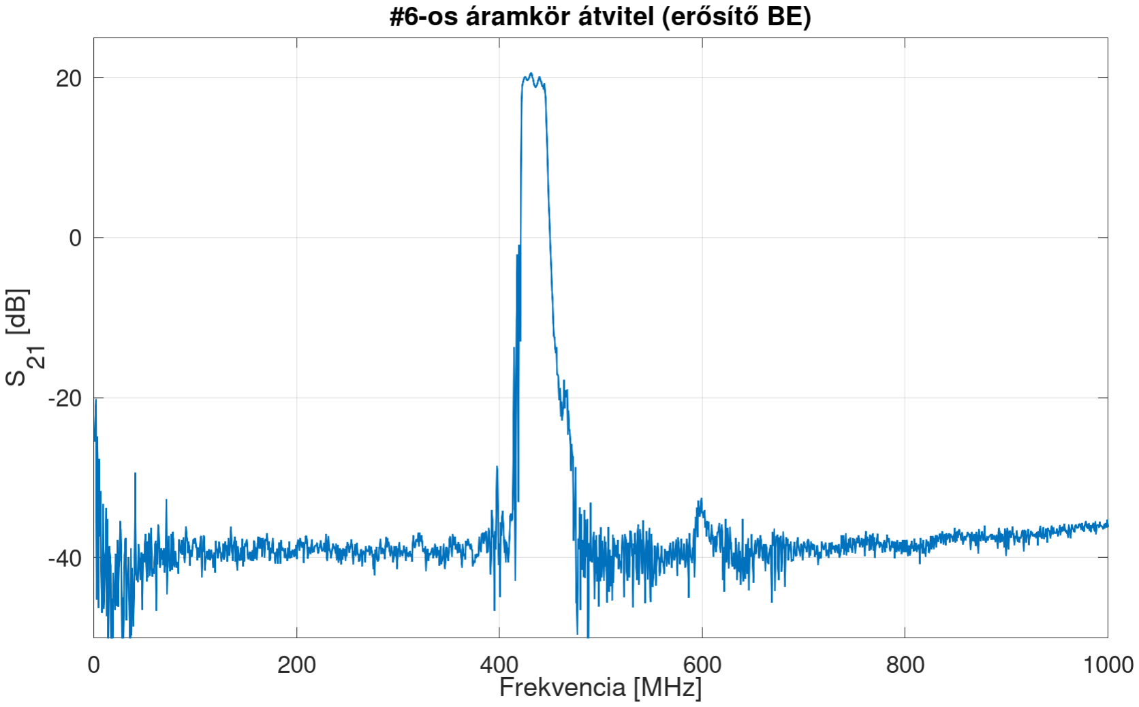
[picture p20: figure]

34. ábra. #6-os erősítő 1 MHz - 1 GHz, erősítő BE

35. ábra. #6-os erősítő 400 MHz - 480 MHz, erősítő BE

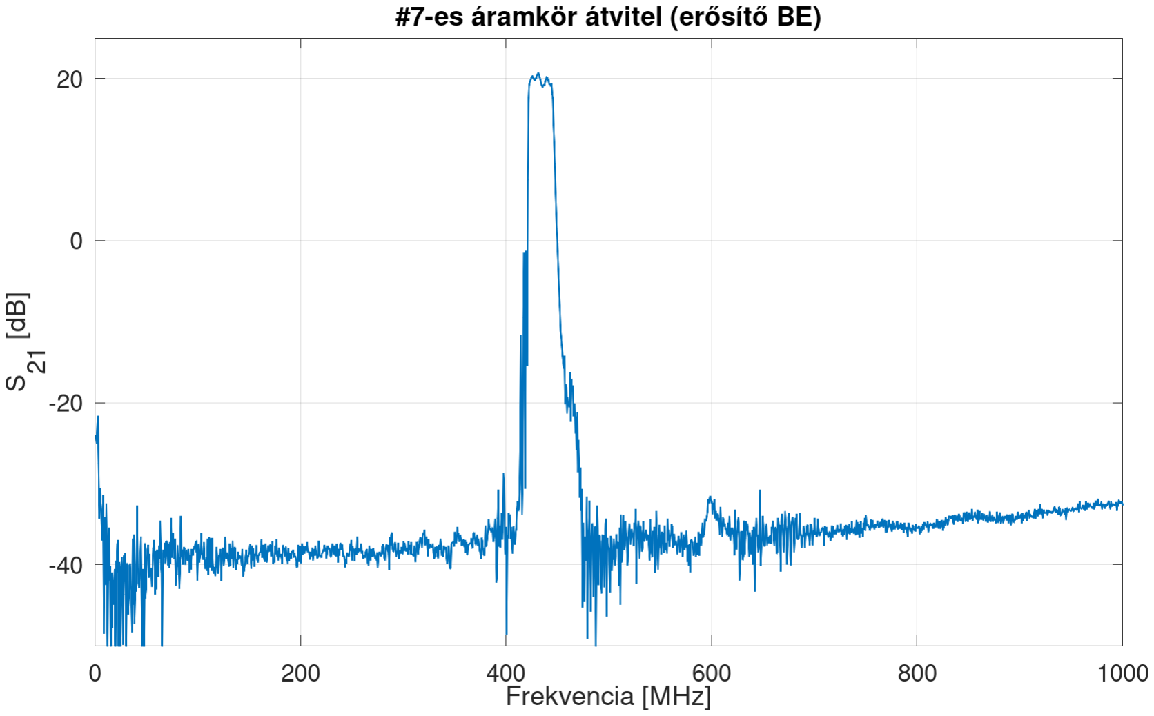
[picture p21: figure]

36. ábra. #7-es erősítő 1 MHz - 1 GHz, erősítő BE

37. ábra. #7-es erősítő 400 MHz - 480 MHz, erősítő BE

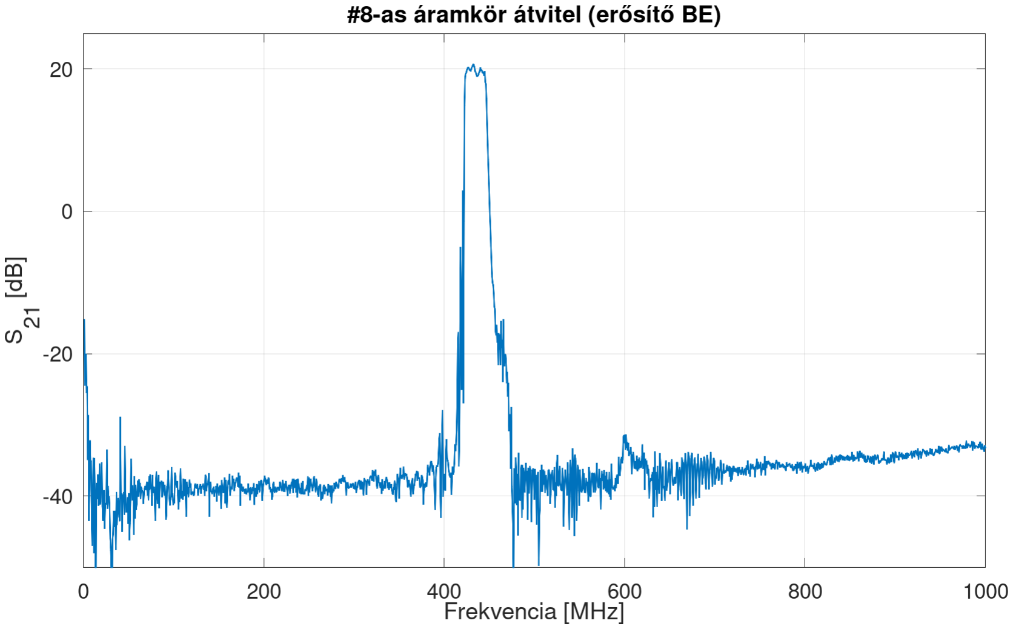
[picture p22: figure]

38. ábra. #8-as erősítő 1 MHz - 1 GHz, erősítő BE

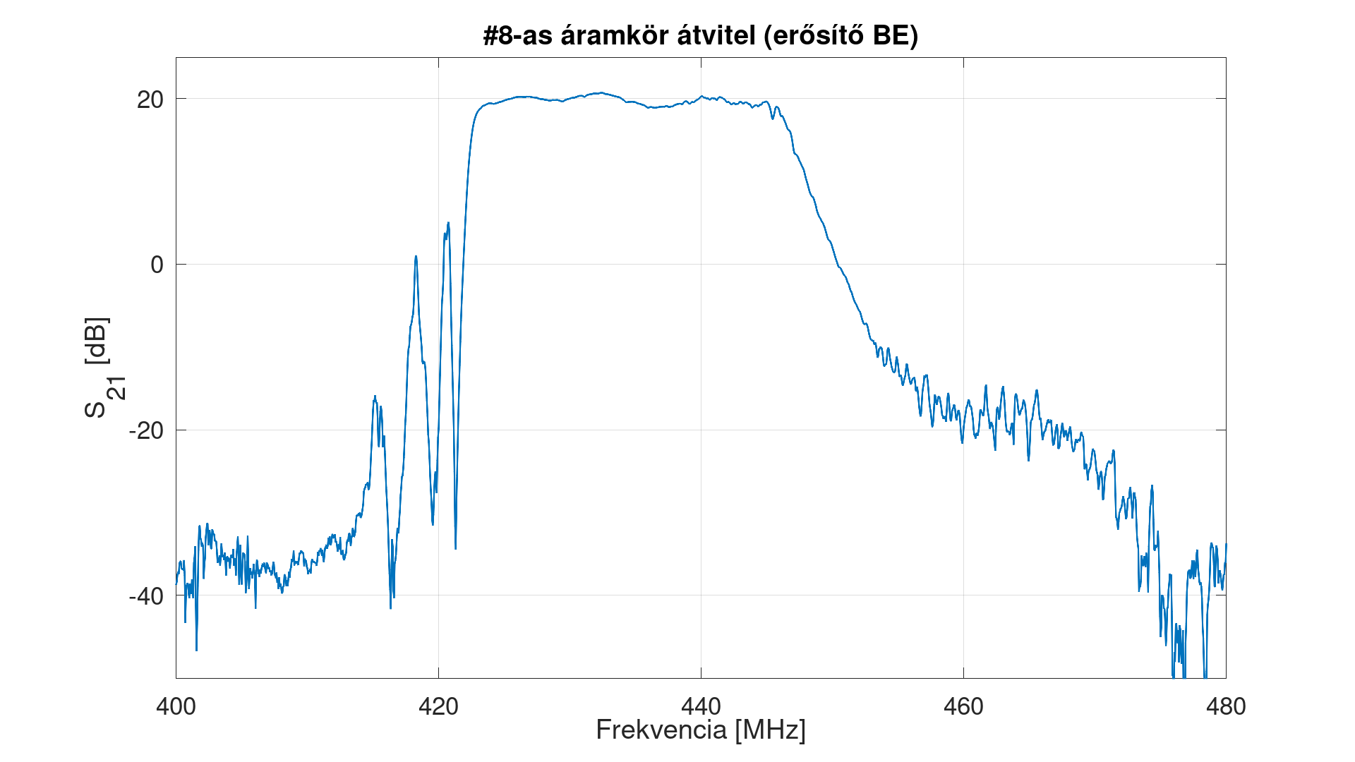
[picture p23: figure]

39. ábra. #8-as erősítő 400 MHz - 480 MHz, erősítő BE

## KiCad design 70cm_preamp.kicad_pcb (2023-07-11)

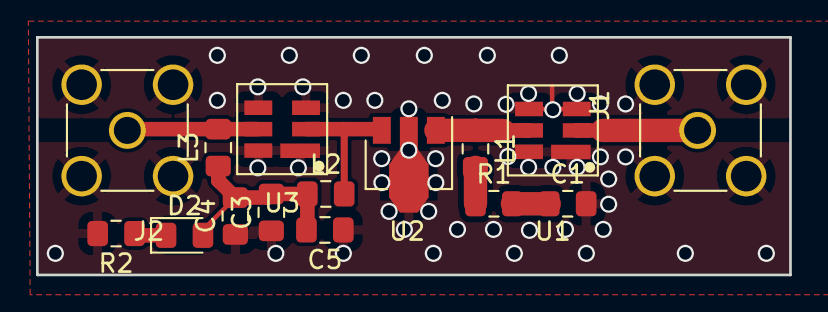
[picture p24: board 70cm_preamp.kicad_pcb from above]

Board: 2 copper layers, 41.8 x 13.2 mm, 15 parts (0 on the bottom side), 9 nets.

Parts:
C1, C3, C4, C5: 330p; C_0805_2012Metric_Pad1.15x1.40mm_HandSolder
D2: LED; LED_0805_2012Metric_Pad1.15x1.40mm_HandSolder
J1: RF_IN; SMA_Amphenol_901-144_Vertical
J2: RF_OUT; SMA_Amphenol_901-144_Vertical
L1, L2, L3: 620n; L_0805_2012Metric_Pad1.15x1.40mm_HandSolder
R1: 150; R_0805_2012Metric_Pad1.15x1.40mm_HandSolder
R2: 330; R_0805_2012Metric_Pad1.15x1.40mm_HandSolder
U1, U3: SF2446E; SF2446E-Filter_Custom_HandSolder
U2: PGA-103+; SOT-89-3

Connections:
GND: C1.2, C3.1, C4.1, C5.1, J1.2 (Ext), J2.2 (Ext), R2.2, U1.1 (G), U1.3 (G), U1.4 (G), U1.6 (G), U2.2, U3.1 (G), U3.3 (G), U3.4 (G), U3.6 (G)
unnamed: C1.1, R1.2
unnamed: L1.1, U1.5 (RF), U2.1
unnamed: J1.1 (In), U1.2 (RF)
unnamed: C3.2, C4.2, C5.2, D2.2 (A), L2.1, L3.1
unnamed: D2.1 (K), R2.1
unnamed: J2.1 (In), L3.2, U3.5 (RF)
unnamed: L2.2, U2.3, U3.2 (RF)
unnamed: L1.2, R1.1

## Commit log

2019-12-17 Initial commity
    [70cm_preamp.kicad_pcb, 70cm_preamp.sch]
2021-02-03 LM7805 added
    [70cm_preamp.sch]
2021-02-09 Optikai tuning
    [70cm_preamp.sch]
2021-02-12 RF alkatreszek
    [70cm_preamp.sch]
2021-03-10 nyák
    [70cm_preamp.kicad_pcb, 70cm_preamp.sch]
2021-03-11 csak tht sma
    [70cm_preamp.kicad_pcb]
2021-03-12 Change via size
    [70cm_preamp.kicad_pcb]
2021-03-12 viák
    [70cm_preamp-B_Cu.gbr, 70cm_preamp-B_Mask.gbr, 70cm_preamp-B_Paste.gbr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]
2021-03-16 Stabilitáshoz RLC
    [70cm_preamp.kicad_pcb, 70cm_preamp.sch]
2021-03-16 0805 RLC
    [70cm_preamp.kicad_pcb, 70cm_preamp.sch]
2021-03-16 új gerberek
    [70cm_preamp-B_Cu.gbr, 70cm_preamp-B_Mask.gbr, 70cm_preamp-Edge_Cuts.gbr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]
2021-04-05 Dokumentáció
    [70cm_preamp.kicad_pcb, 70cm_preamp.sch]
2021-04-12 Zárójelentés
    [70cm_preamp.sch]
2023-07-06 Add a few parts
    [70cm_preamp-B_Cu.gbr, 70cm_preamp-B_Mask.gbr, 70cm_preamp-Edge_Cuts.gbr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]
2023-07-06 Improve inductor places and resolve throughPCB LED issues
    [70cm_preamp.kicad_pcb]
2023-07-10 final checks
    [70cm_preamp.kicad_pcb]
2023-07-10 Label corrections
    [70cm_preamp.kicad_pcb]
2023-07-11 Fix LED window
    [70cm_preamp.kicad_pcb]
2023-07-11 fix gnd
    [70cm_preamp.kicad_pcb]
